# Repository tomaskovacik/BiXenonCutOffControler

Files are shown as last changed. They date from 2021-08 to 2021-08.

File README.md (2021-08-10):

# BiXenonCutOffControler

Simple board which enable bi-xenon cutoff selenoid only if low beams are turned on or disable it when low beams are turned off. When your car is using [PWM](https://en.wikipedia.org/wiki/Pulse-width_modulation) to drive your high beam bulbs at ~30% to act as daytime driving lights, connecting bixenon cuttoff selenoid paralel to high beam bulb will cause nasty rattling noise of this selenoid. 

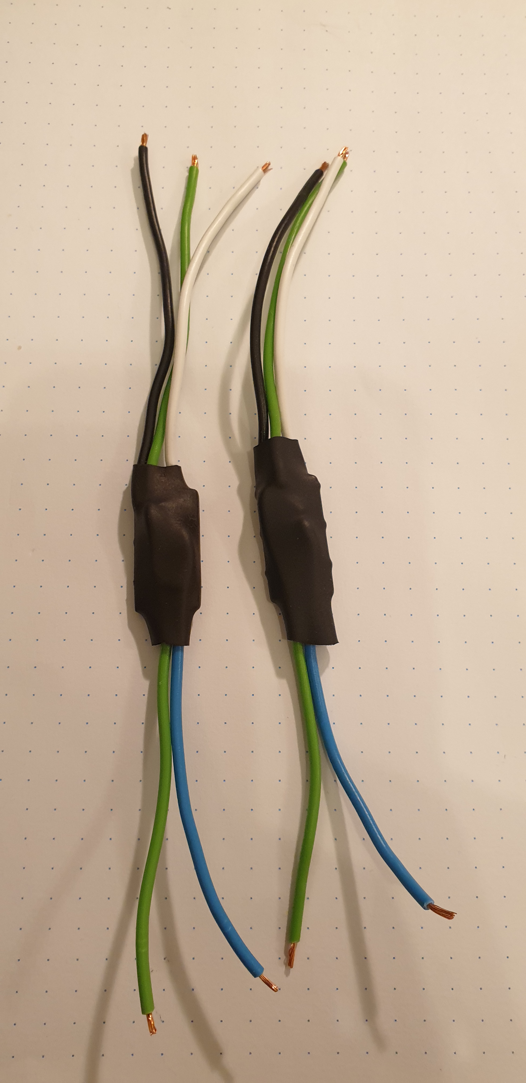
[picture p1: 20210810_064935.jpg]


# Schematics

Single Nchannel mosfet is turned on when low beams are enabled. This mosfet grounds one side of selenoid which is then turned on when high beams are used.

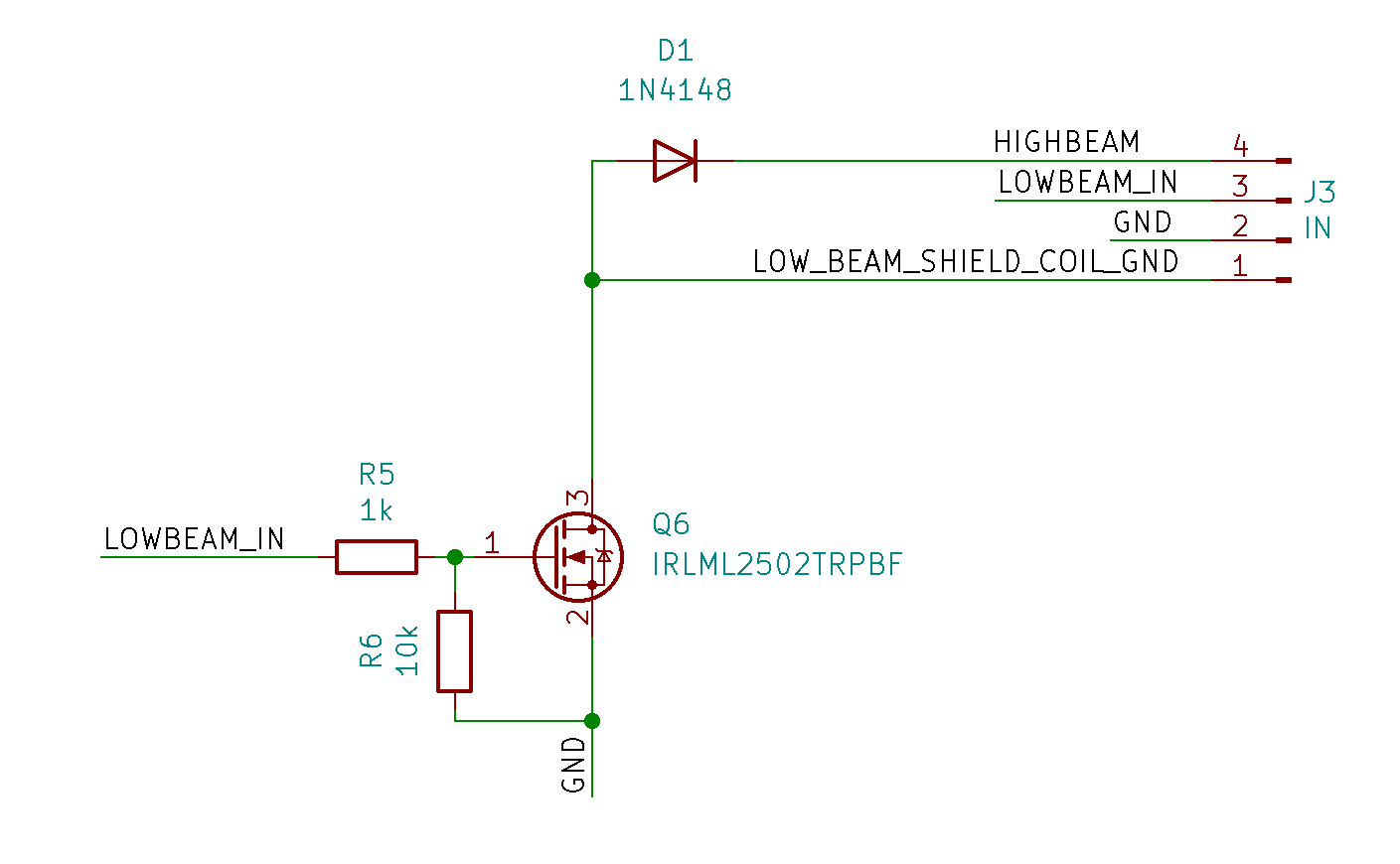
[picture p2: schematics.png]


# In action

https://youtu.be/b0E2H7acrZI



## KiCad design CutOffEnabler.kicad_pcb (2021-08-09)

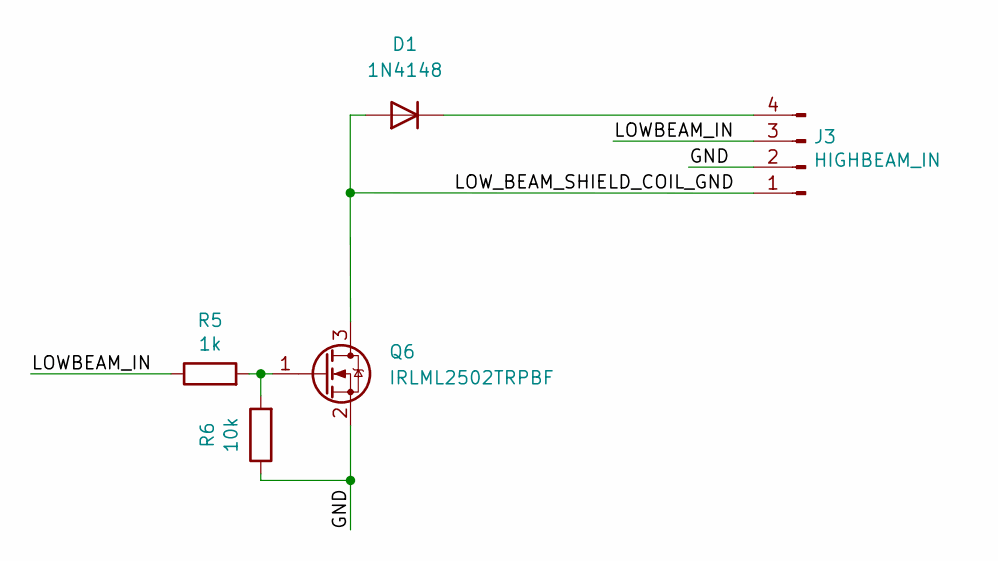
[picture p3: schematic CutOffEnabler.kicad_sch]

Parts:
D1: 1N4148; D_DO-35_SOD27_P7.62mm_Horizontal
J3: HIGHBEAM_IN; Molex_MiniFit-JR-5569-04A2_2x02x4.20mm_Angled
Q6: IRLML2502TRPBF; SOT-23
R5: 1k; R_0805_HandSoldering
R6: 10k; R_0805_HandSoldering

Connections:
/GND: J3.2, Q6.2 (S), R6.1
/LOWBEAM_IN: J3.3, R5.1
/LOW_BEAM_SHIELD_COIL_GND: D1.2 (A), J3.1, Q6.3 (D)
unnamed: D1.1 (K), J3.4
unnamed: Q6.1 (G), R5.2, R6.2

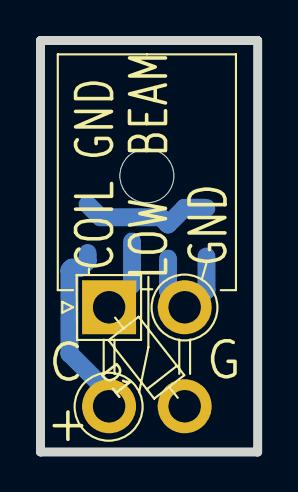
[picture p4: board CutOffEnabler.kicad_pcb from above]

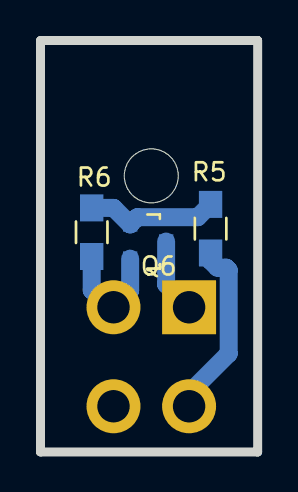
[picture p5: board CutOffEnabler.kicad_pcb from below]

Board: 2 copper layers, 12.1 x 22.9 mm, 5 parts (3 on the bottom side), 5 nets.

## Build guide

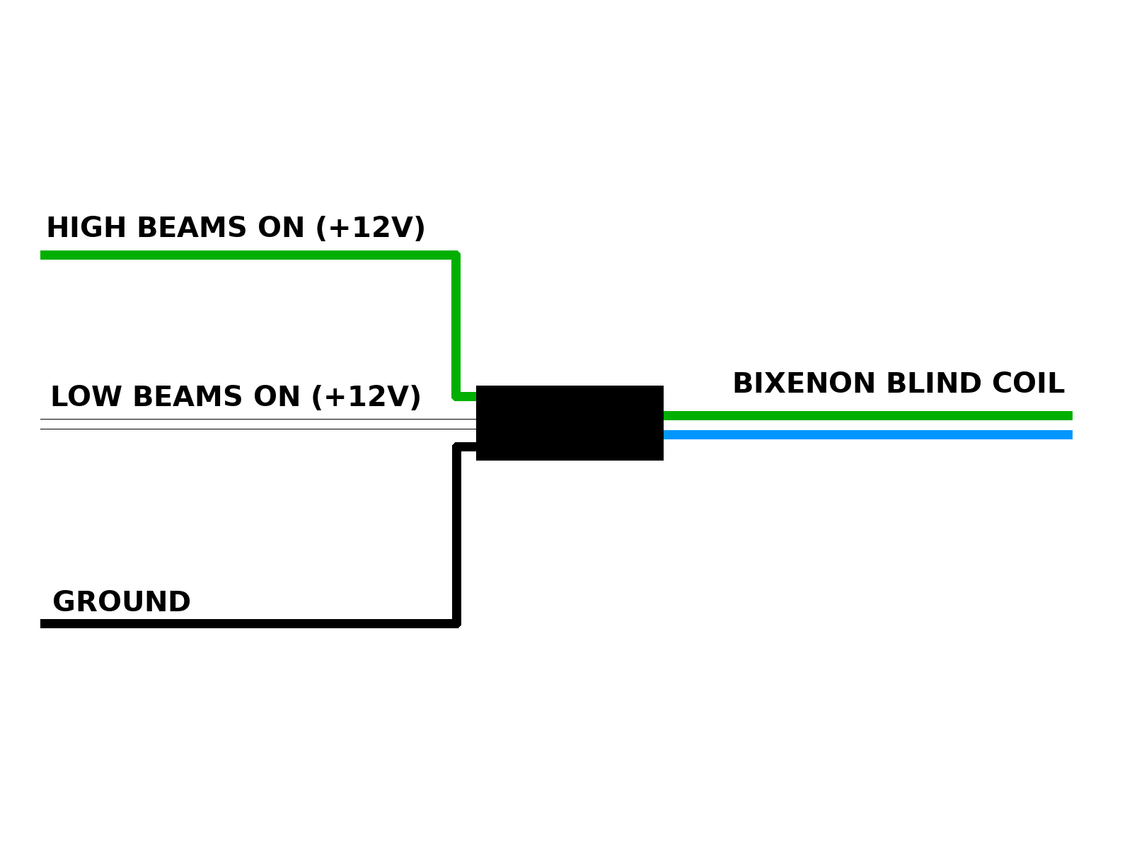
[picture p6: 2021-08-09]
howtoconnect.png
